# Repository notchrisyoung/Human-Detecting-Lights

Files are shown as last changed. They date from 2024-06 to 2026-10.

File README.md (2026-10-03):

# Human-Detecting Lights

Room lights that turn themselves on when someone is actually *in* the room, and off when they leave. It uses a **24 GHz mmWave presence sensor (HLK-LD2410C)** rather than a PIR, so it keeps the lights on while you're sitting still. When presence is detected, an ESP32 fades up a 12 V LED strip and switches on a **Kasa HS200 smart light switch** over Wi-Fi. When the room empties, everything fades back off.

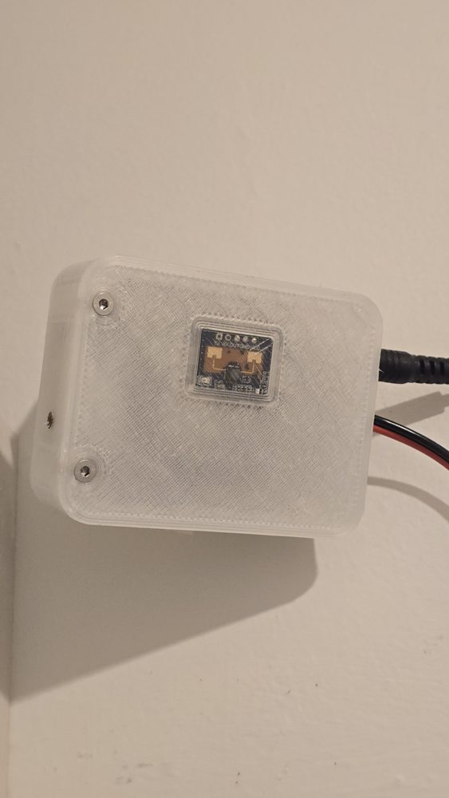
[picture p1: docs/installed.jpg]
The sensor enclosure mounted on a wall


*Mounted on the wall. The LD2410C radar sits behind the window in the lid.*

## How it works

- The LD2410C's presence output pin is read once a second.
- **Someone present →** the LED strip fades up (PWM through a MOSFET) and the Kasa switch is turned on.
- **Room empty →** the Kasa switch turns off and the strip fades down to off.
- **Night mode (10:00pm–06:00am):** the strip comes on at a dimmer level (`LED_NIGHT_BRIGHTNESS`) and the Kasa switch is left **off**, so you get a soft night light instead of the main room lights.
- Time comes from NTP, with a POSIX time-zone string (`PST8PDT,...` by default).
- If the Kasa switch isn't found at boot, the sketch keeps re-scanning the network for it.

## Hardware

- ESP32 dev board (plus a GPIO breakout board)
- HLK-LD2410C mmWave radar presence sensor
- Kasa Smart Light Switch HS200
- 12 V LED light strip and a 12 V power supply
- Logic-level MOSFET and resistors to drive the strip
- 3D-printed enclosure: see [Enclosure](#enclosure)

### Pins

| Signal | ESP32 GPIO |
|---|---|
| LED strip PWM (to MOSFET gate) | 27 |
| LD2410C presence output | 12 |

## Enclosure

| Inside | Closed up |
|---|---|
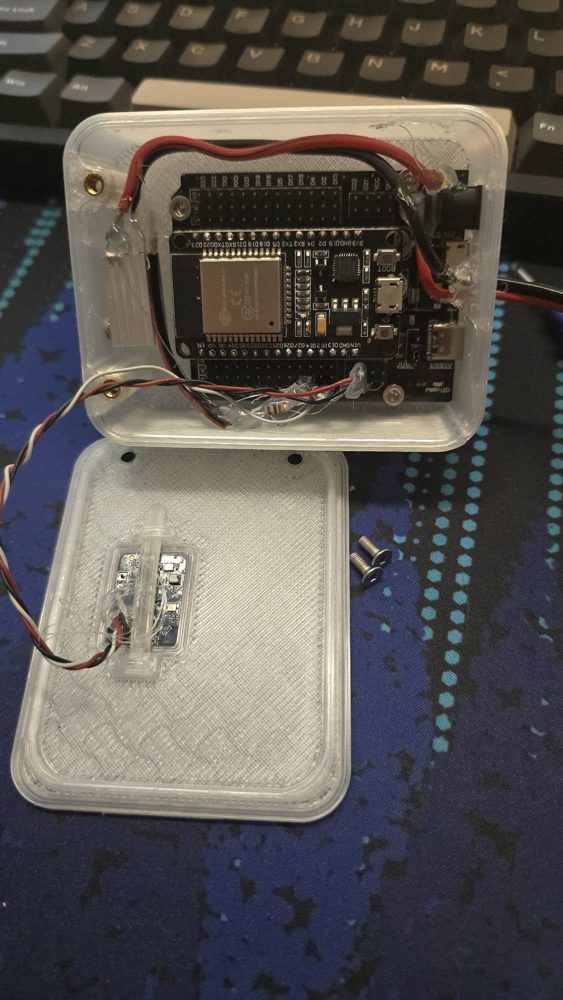
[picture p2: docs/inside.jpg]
The enclosure opened up
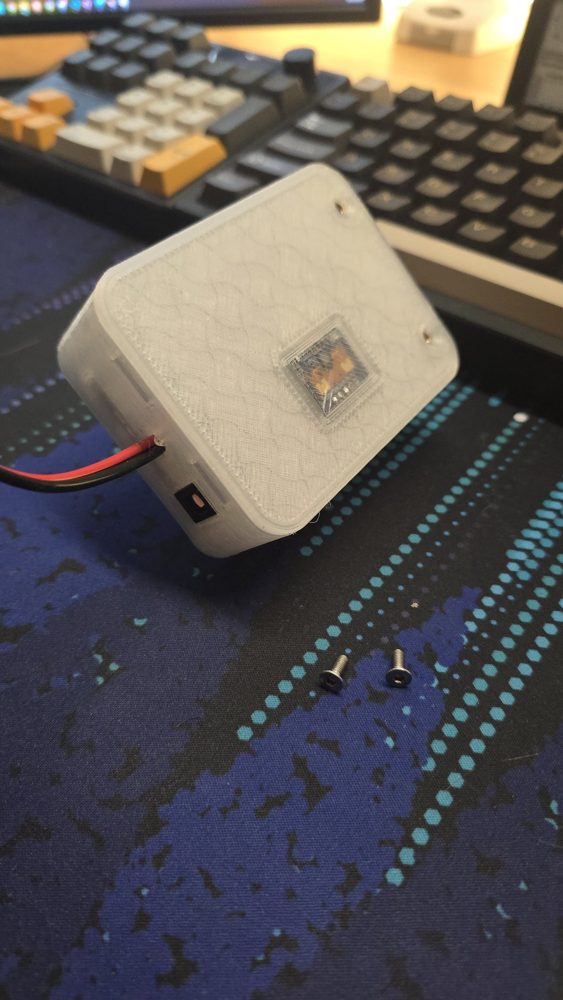
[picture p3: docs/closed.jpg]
The enclosure closed
|  |  |
| The ESP32 on a breakout board, screwed into the holder, with the LED-strip MOSFET on the left. The LD2410C is glued into the pocket in the lid and held by the printed bar. The lid screws into brass heat-set inserts. | Closed up: the radar shows through the window in the lid. The power jack and the LED-strip leads come out of the side. |

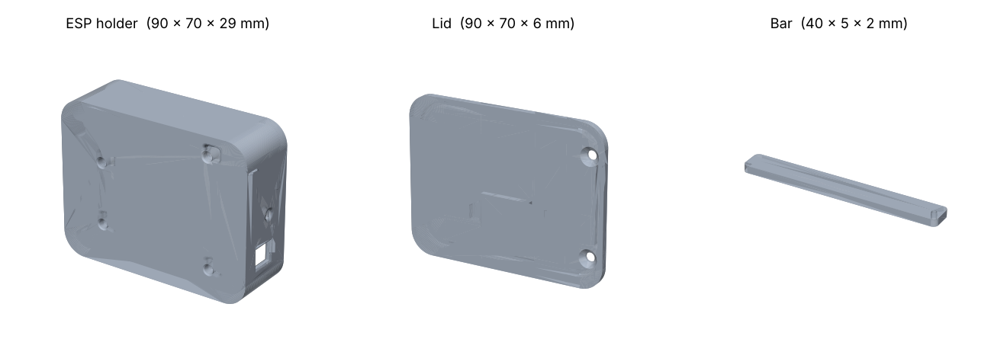
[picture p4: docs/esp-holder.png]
ESP holder, lid and bar


The printable parts are in `STL Files/`:

| File | Part |
|---|---|
| `Big ESP holder.STL` | Main case, 90 × 70 × 29 mm. Holds the ESP32 breakout board, with a cut-out for the power jack |
| `Big ESP holder lid.STL` | Lid with the pocket and window for the LD2410C |
| `bar.STL` | Bar that holds the LD2410C in the lid's pocket |

GitHub can show the STL files in 3D: open one there to rotate it.

## Setup

This is a [PlatformIO](https://platformio.org/) project; the VS Code extension is the easiest way to use it. `platformio.ini` sets the board and pins the libraries, so there's nothing to install by hand:

| Library | Version | Notes |
|---|---|---|
| [KasaSmartPlug](https://github.com/kj831ca/KasaSmartPlug) | pinned to a commit | Not in the PlatformIO registry, so it's pulled from GitHub |
| ArduinoJson | 6.x | KasaSmartPlug uses the v6 API |
| Arduino-ESP32 core | 2.x (`espressif32@6.9.0`) | The firmware uses the `ledcSetup` PWM API, which core 3.x removed |

1. Copy `include/secrets.example.h` to `include/secrets.h` and set:
   - `WIFI_SSID` / `WIFI_PASSWORD`: your Wi-Fi
   - `SWITCH_NAME`: the name of your Kasa switch exactly as it appears in the Kasa app

   `secrets.h` is git-ignored, so your Wi-Fi password can't be committed by accident.
2. Optional, in `src/main.cpp`: `time_zone` (POSIX TZ string), `LED_DAY_BRIGHTNESS`, `LED_NIGHT_BRIGHTNESS`, `START_NIGHT`, `END_NIGHT`.
3. `pio run -t upload`, then `pio device monitor`. The serial monitor (115200) lists every Kasa device found on the network, which helps if the switch name doesn't match.

## Files

| Path | Purpose |
|---|---|
| `src/main.cpp` | ESP32 firmware |
| `include/secrets.example.h` | Template for your Wi-Fi details and switch name |
| `platformio.ini` | Board, build settings and libraries |
| `STL Files/` | 3D-printable enclosure parts (see [Enclosure](#enclosure)) |
| `docs/` | README images |

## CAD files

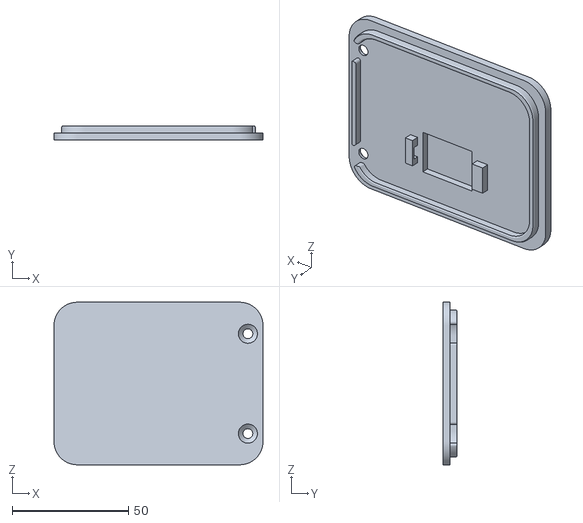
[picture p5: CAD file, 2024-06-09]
STL Files/Big ESP holder lid.STL
90.0 x 6.00 x 70.0

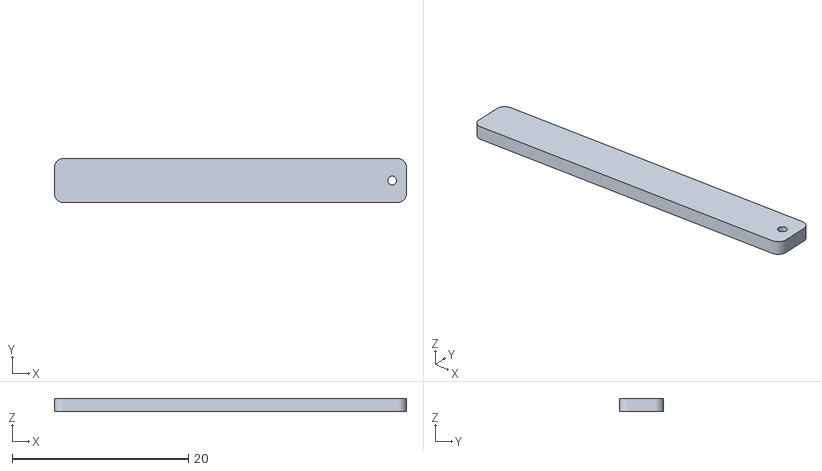
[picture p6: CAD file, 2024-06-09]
STL Files/bar.STL
40.0 x 5.00 x 1.50

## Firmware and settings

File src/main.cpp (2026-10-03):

#include <Arduino.h>
#include <KasaSmartPlug.h>
#include <WiFi.h>
#include "time.h"
#include "esp_system.h"
#include "esp_sntp.h"

// Wi-Fi details and the Kasa switch name live in include/secrets.h, which is
// git-ignored. Copy include/secrets.example.h to include/secrets.h to set them.
#if __has_include("secrets.h")
#include "secrets.h"
#else
#warning "secrets.h not found - using the placeholder values from secrets.example.h"
#include "secrets.example.h"
#endif

// Pins
#define LED_PIN              27
#define MOTION_PIN           12

// Hardware Config
#define PWM_FREQ    5000
#define PWM_CHANNEL 1
#define PWM_RES     8

// Config Settings
#define LED_DAY_BRIGHTNESS   255
#define LED_NIGHT_BRIGHTNESS 100
#define START_NIGHT          22
#define END_NIGHT            6
#define LIGHT_TIMEOUT        5
#define LED_FADE_TIME        2

// WIFI
const char* ssid       = WIFI_SSID;
const char* password   = WIFI_PASSWORD;

// Time
const char* ntpServer1 = "pool.ntp.org";
const char* ntpServer2 = "time.nist.gov";
const char* time_zone = "PST8PDT,M3.2.0,M11.1.0";  // POSIX TZ rule: US Pacific, with daylight saving
struct tm timeinfo;

// WIFI Switch
KASAUtil kasaUtil;
KASASmartPlug *lightSwitch = NULL;

// Timer
hw_timer_t *My_timer = NULL;

// Flags
bool motionFlag = false;
bool timeFlag = false;
bool turnOnLights = true;
bool lights_are_on = false;


/*--------------- Functions -----------------*/
void printLocalTime() {
  if(!getLocalTime(&timeinfo)){
    Serial.println("No time available (yet)");
    return;
  }
  Serial.println(&timeinfo, "%A, %B %d %Y %H:%M:%S");
  int current_min = (timeinfo.tm_hour * 60) + timeinfo.tm_min;
  Serial.println(current_min);
}

void lightsOn() {
  if(turnOnLights){
    if(lightSwitch != NULL){
      lightSwitch->SetRelayState(1);
    }
    for(int dutyCycle = ledcRead(PWM_CHANNEL); dutyCycle <= LED_DAY_BRIGHTNESS; dutyCycle++){
      ledcWrite(PWM_CHANNEL, dutyCycle);   
      delay(5);
    }
    ledcWrite(PWM_CHANNEL, LED_DAY_BRIGHTNESS); 
  }
  else{
    for(int dutyCycle = ledcRead(PWM_CHANNEL); dutyCycle <= LED_NIGHT_BRIGHTNESS; dutyCycle++){
      ledcWrite(PWM_CHANNEL, dutyCycle);
      delay(8);
    }
    ledcWrite(PWM_CHANNEL, LED_NIGHT_BRIGHTNESS); 
  }
}

void lightsOff() {
  if(lightSwitch != NULL){
    lightSwitch->SetRelayState(0);
  }
  for(int dutyCycle = ledcRead(PWM_CHANNEL); dutyCycle >= 0; dutyCycle--){
    ledcWrite(PWM_CHANNEL, dutyCycle);   
    delay(15);
  }
  ledcWrite(PWM_CHANNEL, 0); 
}

void IRAM_ATTR motionISR() {
  motionFlag = true;
}

void IRAM_ATTR onTimer() {
  timeFlag = true;
}

/*--------------- Setup -----------------*/
void setup() {
  Serial.begin(115200);

  // Time server setup
  sntp_servermode_dhcp(1);    // (optional)
  configTzTime(time_zone, ntpServer1, ntpServer2);

  // Connect to WiFi
  Serial.printf("Connecting to %s ", ssid);
  WiFi.begin(ssid, password);
  while (WiFi.status() != WL_CONNECTED) {
      delay(500);
      Serial.print(".");
  }
  Serial.println(" CONNECTED");
  
  // Switch setup
  int found;
  found = kasaUtil.ScanDevices();
  Serial.printf("\r\n Found device = %d", found);
  for (int i = 0; i < found; i++)
  {
    KASASmartPlug *p = kasaUtil.GetSmartPlugByIndex(i);
    if (p != NULL)
    {
      Serial.printf("\r\n %d. %s IP: %s Relay: %d", i, p->alias, p->ip_address, p->state);
    }
  }
  lightSwitch = kasaUtil.GetSmartPlug(SWITCH_NAME); 
  
  Serial.printf("\r\n lightSwitch = %p", (void *)lightSwitch);
  // Motion sensor setup
  pinMode(MOTION_PIN, INPUT);

  // LED setup
  ledcSetup(PWM_CHANNEL, PWM_FREQ, PWM_RES);
  ledcAttachPin(LED_PIN, PWM_CHANNEL);

  Serial.println("Setup Finished");
  printLocalTime();
}

/*--------------- Main Loop -----------------*/
void loop() {
  // Turn lights on 
  Serial.println(digitalRead(MOTION_PIN));
  if(!lights_are_on && digitalRead(MOTION_PIN)){
    lightsOn();
    lights_are_on = true;
  }
  // Turn lights off if time is up
  if(lights_are_on && !digitalRead(MOTION_PIN)){
    lightsOff();
    lights_are_on = false;
  }
  // Scan for the device if it was not found at start
  if(lightSwitch == NULL){
    kasaUtil.ScanDevices(200);
    lightSwitch = kasaUtil.GetSmartPlug(SWITCH_NAME); 
  }
  // Check time of day
  if(getLocalTime(&timeinfo)){
    int current_min = (timeinfo.tm_hour * 60) + timeinfo.tm_min;
    turnOnLights = ((END_NIGHT * 60 < current_min) && (current_min < START_NIGHT * 60));
  }
  delay(1000);
}

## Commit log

2026-10-03 Convert to a PlatformIO project
    - LightController/LightController.ino -> src/main.cpp
    - Wi-Fi details and the Kasa switch name move to a git-ignored include/secrets.h
    - Libraries pinned in platformio.ini (KasaSmartPlug from GitHub, ArduinoJson 6)
    - README setup steps updated for PlatformIO
    Claude-Session: https://claude.ai/code/session_01AUPozFroVL22kzHz3JWSUB
2026-10-03 Add the sensor enclosure (case, spacer, lid) and an install photo
    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
    [Enclosure case.STL, Enclosure lid.STL, Enclosure spacer.STL]
2026-10-03 Add build photos and describe the ESP holder enclosure in the README
    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
2026-10-03 Remove the duplicate 58 mm enclosure files
    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
    [Enclosure case.STL, Enclosure lid.STL, Enclosure spacer.STL]
